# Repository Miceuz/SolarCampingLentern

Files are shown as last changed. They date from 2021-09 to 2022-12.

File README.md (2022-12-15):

# Open source Solar Camping Lantern

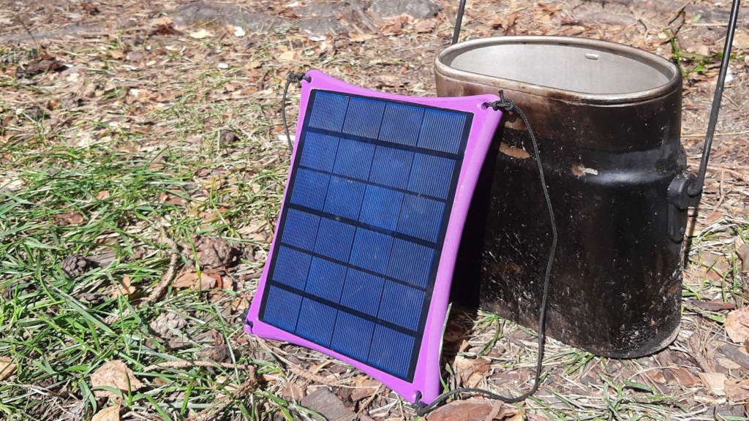
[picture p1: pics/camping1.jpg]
Open source Solar Camping Lantern


## Background

I started seeing a lot of disposable electronic cigarettes being used. As everyone knows, those devices contain perfectly rechargeable LiPo battery. And I've seen them thrown away everywhere - on streets, in general waste thrash cans, etc. While a lot of my friends have successfully refilled juice and re-charged the battery, the devices are not built to last - heating coil dies after several re-uses anyway. I have decided to look for a way to recycle those batteries. 

So I have decided to make a lantern for my camping needs and also investigate a product parameter space. The idea popped in to my mind during a summer music festival, actually. When you camp with your friends and need a bit of extra light in the camp at night. It was a sunny summer, so of course I had to have it solar powered. Provided unlimited supply of batteries, can it be self sufficient in it's power needs just from solar energy while still being manageable in camp environment?

It's always a good idea to check what's available at the market. Maybe there is a product on the market that does just that? Just a piece of my expenses, not worth spending my time?

## Initial requirements

 * Light output: ~100lm
 * Run time: min 4h
 * Battery: LiPo 3.7V ~2000mAh
 * Charging time: 6h

I have gauged the amount of needed light from my Lumilight pocket torch I have lost and my "cyclope" torch from Decathlon I got this year. 100lm is not a huge amount of light but still not that bad - it's enough to see people and stuff around, human eye is logarithmic and adapts to low light conditions.

Run time is a modest guess from a festival scenario - you might need light from 11 at night to 3 in the morning, roughly.

Charging time is a lazy day camping, maybe I will remember to pull it out and put on a sun sometime. It's not full effective sun time, just general time the device spends in sun semi-kinda-charging.

## Case studies

### [BioLite SunLight 100](https://www.bioliteenergy.com/products/sunlight-100?variant=1142597386254)

  * Light output: 100lm max
  * Battery: 750mAh LiPo
  * Run time: 3h
  * Solar pannel: 0.45W
  * Charging time: 7h
  * Dimensions: 85x86x23 mm
  * Weight: 95g
  * Price: 20$

### [MPOWERD Luci Outdoor 2.0](https://mpowerd.com/products/luci-outdoor-2-0-f2017)

 * Light output: 75lm
 * Battery: 1000mAh
 * Run time: 6h
 * Charging time: 7h
 * Dimensions: 127mm dia, 25mm height
 * Weight: 125g
 * Price: 24$

### [MPowerd Luci Solar String Lights](https://mpowerd.com/products/string-lights)

 * Light output: 100lm
 * Battery: 2000mAh
 * Charging time: 16h
 * Run time: 5h
 * Dimensions: 127mm dia, 50mm height
 * Weight: 320g
 * Price: 50$

There are devices that target the same light output I want. Some of these specifications are inferred as not all manufacturers provide all the information I needed. SunLight 100 does almost exactly what I want, but solar battery this size barely will produce 8.3Wh needed in 7h of charging time. All in all solar in all of these products seems to be a nice addition to USB charging, not the main power provider. 

Also I have bought some not-so-cheap crap from local hardware store that pretended like it can do what I want, but solar battery was total crap in those, outputting mere single digit milli-amps.

Thus, I have easily convinced myself that this is well worth as a hobby project. Besides, had to use those batteries up! So, with the battery sourcing question sorted out, let's not think about price too much and look what happens if we push on the light output efficiency and solar input efficiency.

## Design

### MPPT options

 * SPV1040T
 * ADP5090ACPZ-2-R7
 * BQ24650
 * [MPPT Solar Panel Controller with DC Converter](https://www.tindie.com/products/electronicstore/mppt-solar-panel-controller-with-dc-converter-2)

In the times of supply chain collapse, choosing a MMPT capable converter chip for storing solar energy to the battery was not an easy thing. They all are either not available or expensive. Luckily I have stumbled on this board by [PC Tech](https://www.tindie.com/stores/electronicstore/) featuring CN3791. Basically this project could have ended just there, as this board was all I needed - I have made my first prototype using it. Although I had to extract a bit more efficiency by having a dedicated led driver, also add some computer control to the thing. 

### Light Source

 * L130-4070003000W21 - Vf = 6V, I = 100mA, Light output = 100lm

It's one of the most efficient LEDs available at electronic distributors at the time. What's interesting and handy is that it's practically voltage controlled - it has a nice shallow IV curve. Provided you extract the heat from them though. They will happily do 100lm at 0.6W, the efficiency is even higher if you run them at half the rating. That's why I have doubled them up in my design.

Also I have decided to throw in a red light source, to see if it might be usable too. Red light does not dazzle humans too much, so it makes a good low level standby light source for the night. I did not want to add additional complication of channel switching for led driver chip, thus decided to power red led directly from MCU pin.

### Photovoltaics

 * [Solar panel](https://www.evita.lt/u-9045-saules-baterijos-modulis-6v-3-5w-165x135mm?search=saul%C4%97s) 6V, 3.5W

These panels, available at local suppliers, looked like a good trade-off between size and output power. Besides, not a lot to choose from, really. I have measured them and they were outputting the rated power, but it dropped drastically with non-perfect orientation to the sun, thus it has to be de-rated significantly. I have guesstimated MPPT point of the panel to be somewhere at 80% of it's open circuit voltage and measured about the same with a potentiometer hooked up to it.

### Power

**If you replicate this design, be warned that battery failure is a risk to be considered!**

 * Battery: 3.7 LiPo, capacity varies: 1.4Wh, 1.85Wh, total capacity up to 11Wh
 * MCU powered directly from battery
 * DC-DC led driver - MCP1664

Batteries are re-used from electronic cigarettes. I don't really know if they retain their safety ratings after they have been re-charged, but people around are re-charging them and I've heard of no fires happening. 

They come with a protection board and I have tried shorting and over-discharging them - seem to work fine, also I've seen my friends ridiculously abusing them with high charge currents on par of 3C. Their longevity is to be proven though as they might not be optimized for a lot of re-charge cycles, but it seems their safety is on par with standards mandatory with CE marking. I am happy to delay their travel to a landfill or a recycler.  

### Operational parameters

 * Energy consumed: 0.1A * 6V * 4h = 2.4Wh
 * Solar power available: 3.5W minus conversion losses
 * Light output: 120lm

It has plenty of solar - 1h of perfect sunlight should provide enough of charge for 4 required hours. Seems to make sense to have more battery capacity, but there is a small trade-off with the weight. It will be interesting to experiment with battery sizes and see what run times are achievable.

### Mechanical construction

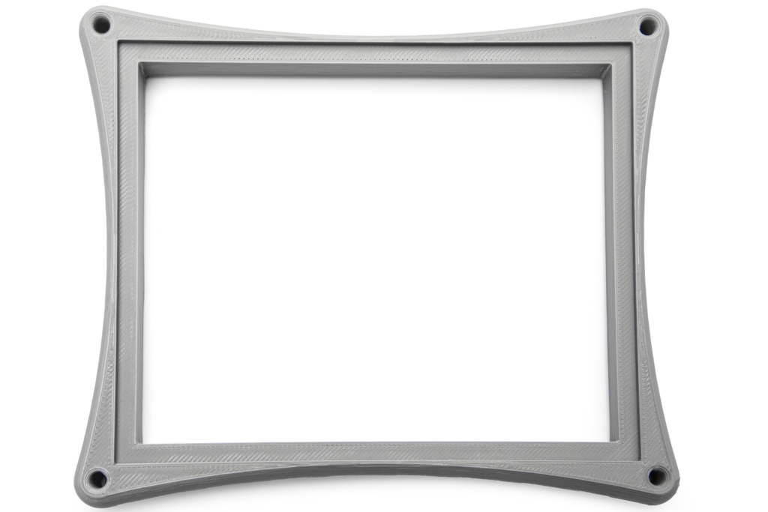
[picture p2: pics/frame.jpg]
Frame of Solar Camping Lantern


Size and shape of the device is dictated by the solar panel. Since I wanted a lot of solar power, I knew I will not be able to make it as compact as commercially available devices. Also mechanical side of things is not my strength, so I went for a simple flat panel. One of use cases for such a light would be as a coaster for a water bottle - that makes a pretty nice low effort table light. Also I've added 4 holes to attach the lantern with rope - to a branch or a tarp. 

All assembly is glue based (blergh!). Batteries are glued to the PCB. PCB is glued and soldered to the solar panel. Both the solar panel and plexiglass are glued to a 3D printed plastic frame.

Considering the usage scenario, of course it should have some level of ingress protection. Provided all glue seams are tight (sic!), the only place for water to seep in is through a button hole. I am going to experiment with printing of the frame from flexible plastics and have the button hole closed, but for the first revision there's going to be a small seam between hole and plunger and IPX6 rated button behind it.

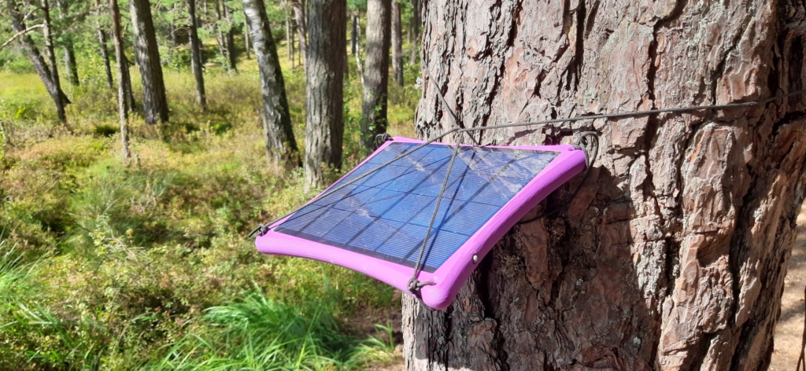
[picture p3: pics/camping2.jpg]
Solar Camping Lantern attached to a tree for charging


### MCU and software

I have chosen my beloved attiny441 - I have a stock of them and I am used to them and it's a relief to spend some time in a simple naive world of 8-bit microcontrollers. It's pretty low power too.

Software functions:

 * On/Off
 * Different levels of lighting
 * Cycle through white and red leds
 * Indicate battery level via charlieplexed leds
 * Auto level reduction on low battery [todo]
 * Fade everywhere [todo]
 * Sky's the limit, what can you do with a single button interface?

### Bells and whistles

 * Charlieplexed leds for battery level indication

### Weight analysis

| Item | Weight, g |
|---|---|
| 3.5W solar panel | 96 |
| Plexiglass | 73 |
| Frame | 56 |
| PCB 0.8mm | 36 |
| Battery 380mAh 7g, 3pack | 22 |
| Electronic components | 4 |
| Glue | 10 |
| **Total** | **297** |

## BOM Price analysis

| Item | Price, € |
|---|---|
| Solar panel | 13 |
| Electronic components | 6.3 |
| PCB | 5.1 |
| Frame | 2 |
| Plexiglass | 0.6 |
| Batteries | 0 |
| **Total** | **27** | 

Prices are for a small batch of 10 units.

## Final specifications

 * Light output: 120lm
 * Battery: LiPo 3.7V up to 4000mAh 
 * Run time: >4h
 * Solar pannel: 3.5W
 * Charging time for 4h run time: 1h (perfect sun conditions)
 * Dimensions: 193x163x15 mm
 * Weight: 297g
 * BOM Price: 27€

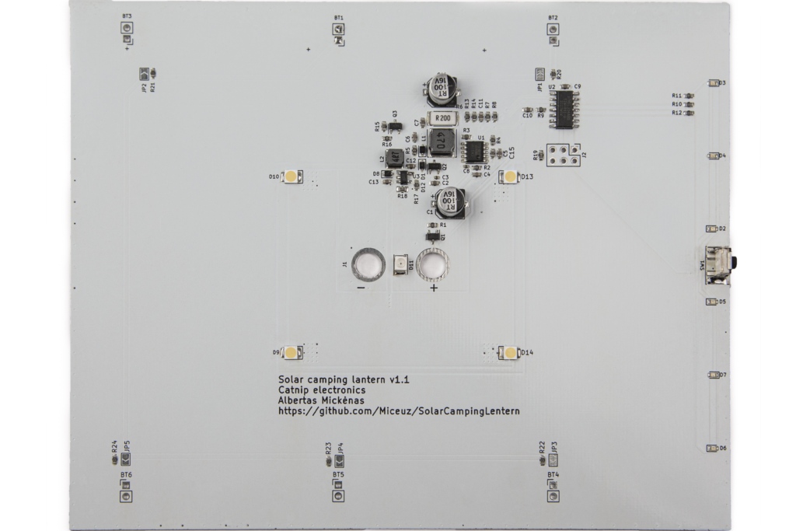
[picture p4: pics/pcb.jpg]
PCB of Solar Camping Lantern


## Conclusion

I took me 3 PCB iterations to get it right, I had to adjust a button position so it's easier to find in the dark, also I had to spread battery level indication leds along the edge so they would be distinguishable behind the plexiglass. Finally I have used 4 while leds instead of two, also spaced out as the single light source was a bit too strong. 

Weight is a concern, but here I am limited to materials I have access to. I have made some improvements by using a 0.8mm PCB, maybe I can make the frame lighter, but the real limiting factors are solar pannel and plexiglass.

I have tried using the first prototype while camping at sunny autumn and it proved to be working very well. Working time with 870mAh battery was a little too short for long autumn evenings at full 100lm, but it was able to fully charge during the next day. Later I brought the panel to a rainy camping trip in December. Panel was barely charging the 5.5Ah battery, but it held almost two evenings allowing us to set up camp, prepare wood and chill under the red light in addition to fire. I think it's not much useful for rainy winter in Easter Europe, but it will be a perfect light for summer camping.

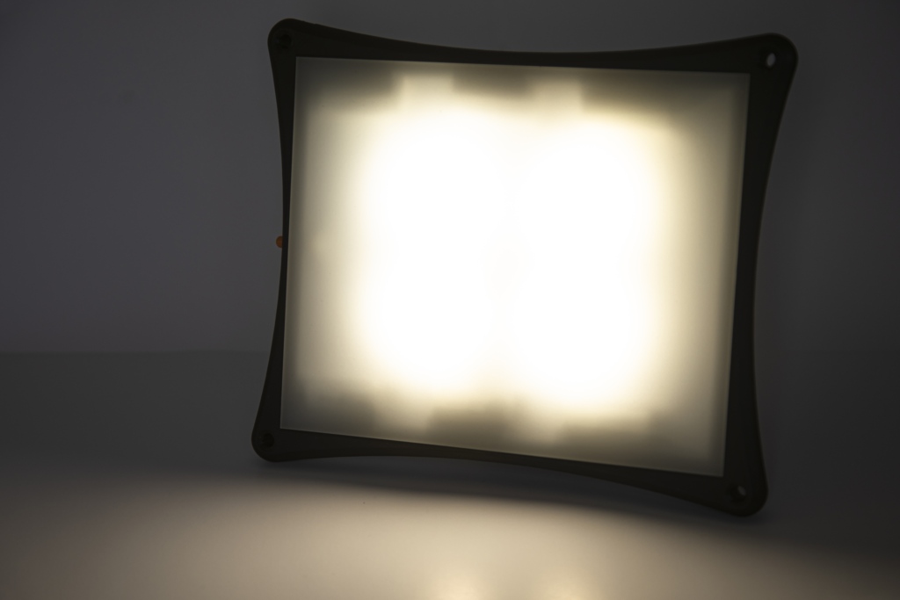
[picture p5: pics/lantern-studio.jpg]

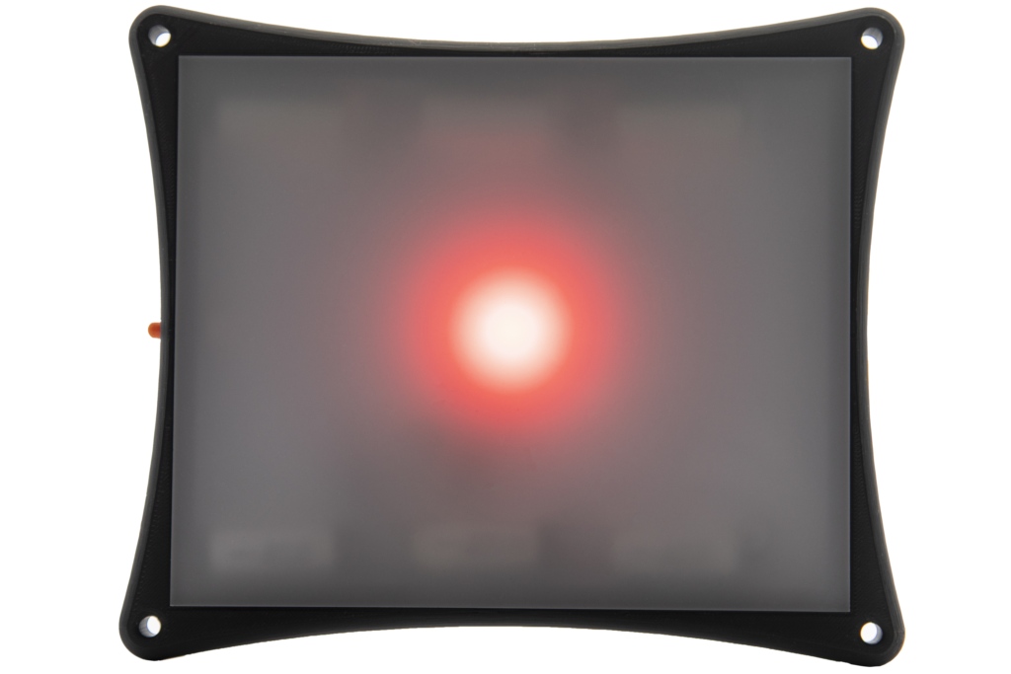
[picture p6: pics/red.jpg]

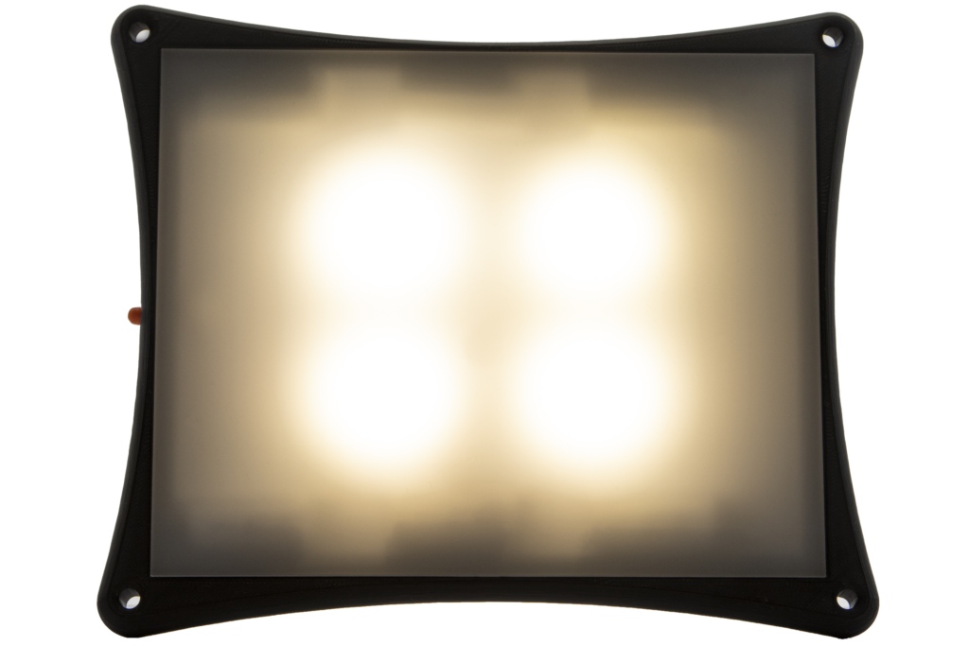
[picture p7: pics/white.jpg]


## Licence

[CERN Open Hardware Licence Version 2 - Strongly Reciprocal](https://ohwr.org/cern_ohl_s_v2.txt)

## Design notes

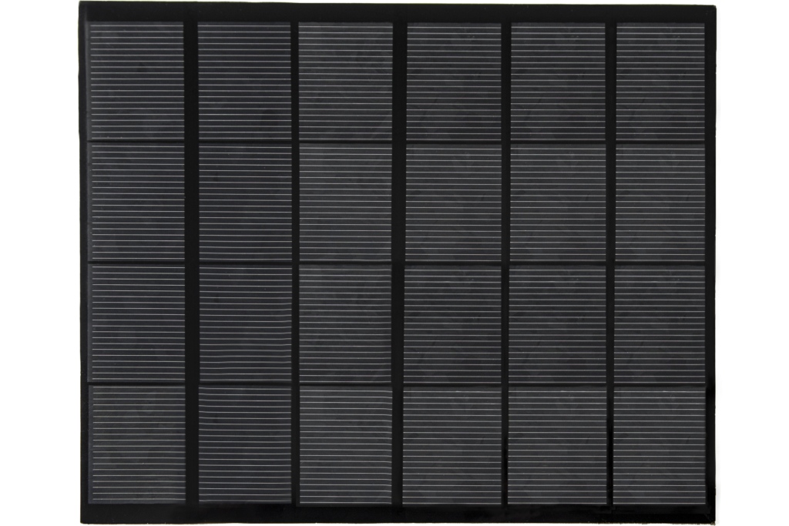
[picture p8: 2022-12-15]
pics/solar-pannel.jpg

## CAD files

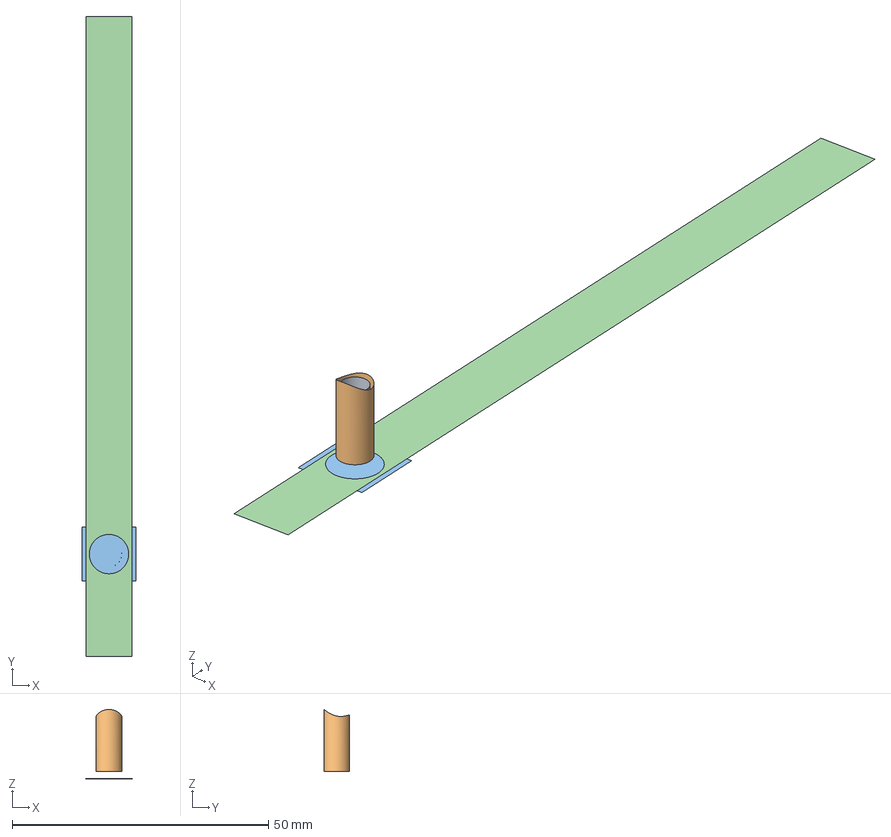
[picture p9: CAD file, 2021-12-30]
mechanical/plunger-assembly.FCStd
10.6 x 125.0 x 13.5 mm
_Element
_Element001
XY_Plane@Body
_Element003

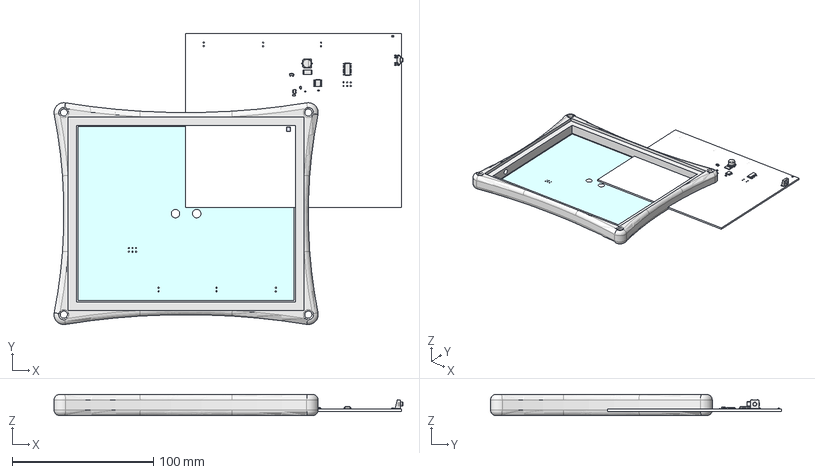
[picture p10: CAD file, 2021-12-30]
mechanical/assembly.FCStd
247.0 x 206.0 x 15.0 mm
D10_3030-017 UNIT SIZE product (Adjust Origin) 26Sept19_c236f93da869
C14_CP_Elec_63x54_Nichicon_5161770a203f
C4_C_0603_1608Metric_8aaf7dfd186b
R1_R_0603_1608Metric_b76f0809609e
D3_D_0603_a9e88e545611
C3_C_0402_1005Metric_6a8e8e6d586b
Q3_SOT_23_0002a45287e3
D11_CLVBA-FKA-CAEDH8BBB7A363_9ca18516bff6
D12_D_SOD_323_f1b1cf5ceba4
R18_R_0805_2012Metric_6b706fde28c5
R6_R_2512_6332Metric_f1aa6a1b5782
U1_SSOP_10_39x49mm_P100mm_f70d7e3d2787
U2_SOIC_14_39x87mm_P127mm_84519712cec0
U3_SOT_23_5_c68c99c74113
SW1_C-1571407-2_2a826a100a5c
_Element
_Element001

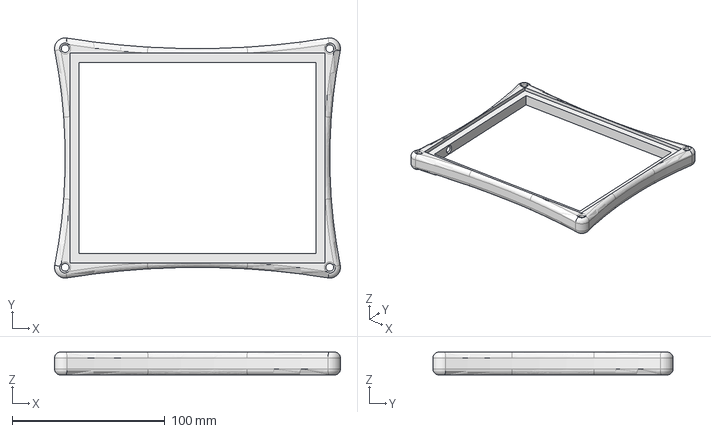
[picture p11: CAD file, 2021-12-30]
mechanical/bezel2-chmfer.FCStd
187.0 x 157.0 x 15.0 mm

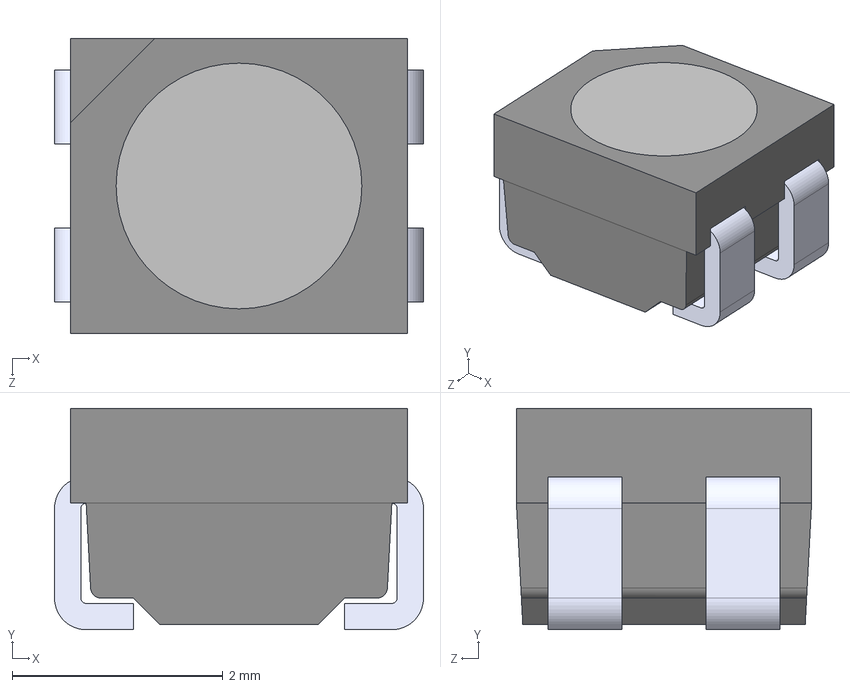
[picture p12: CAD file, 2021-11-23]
solar_lantern/3d/CLA1B-MKW-XD0E0E73.STEP
3.50 x 2.10 x 2.80 mm

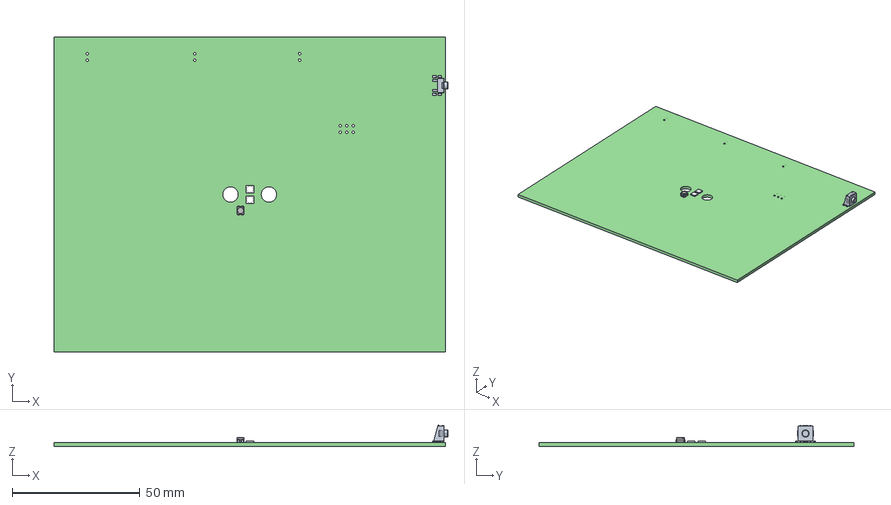
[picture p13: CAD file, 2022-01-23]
solar_lantern/solar_lantern.step
154.0 x 123.0 x 8.35 mm
solar_lantern PCB

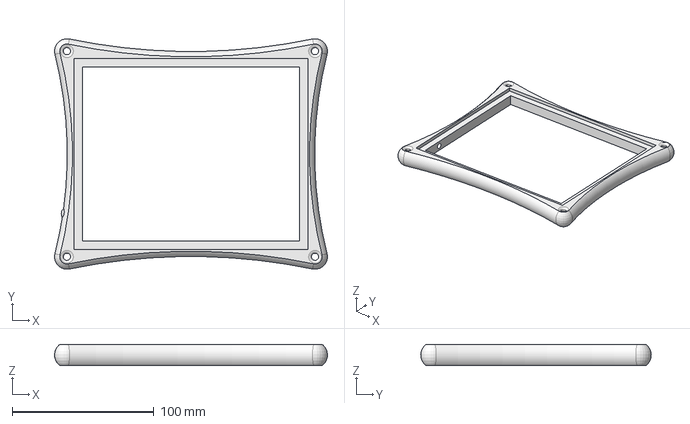
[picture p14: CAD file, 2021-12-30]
mechanical/bezel4.FCStd
192.8 x 162.8 x 15.0 mm

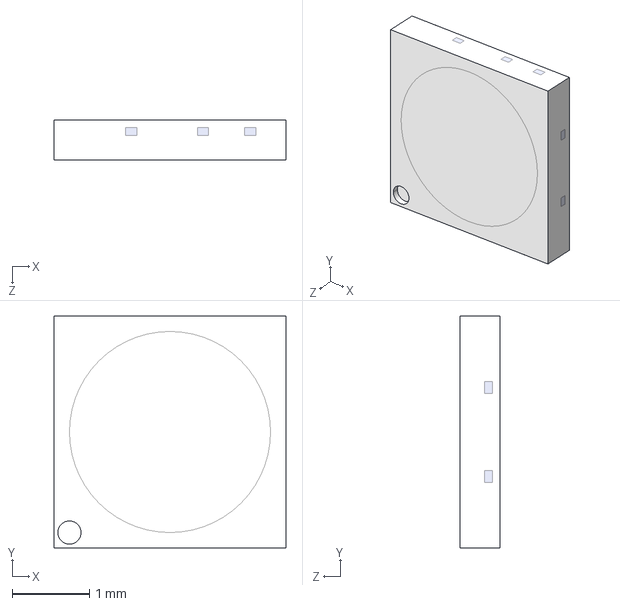
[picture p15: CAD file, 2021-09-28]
solar_lantern/3d/LUXEON 3030 2D Round LES.step
3.00 x 3.00 x 0.523 mm

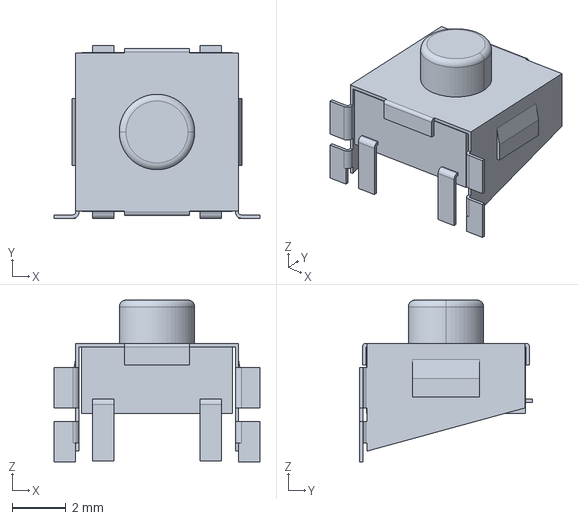
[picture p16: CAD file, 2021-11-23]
solar_lantern/c-1571407-2-j-3d.stp
7.64 x 6.40 x 6.00 mm

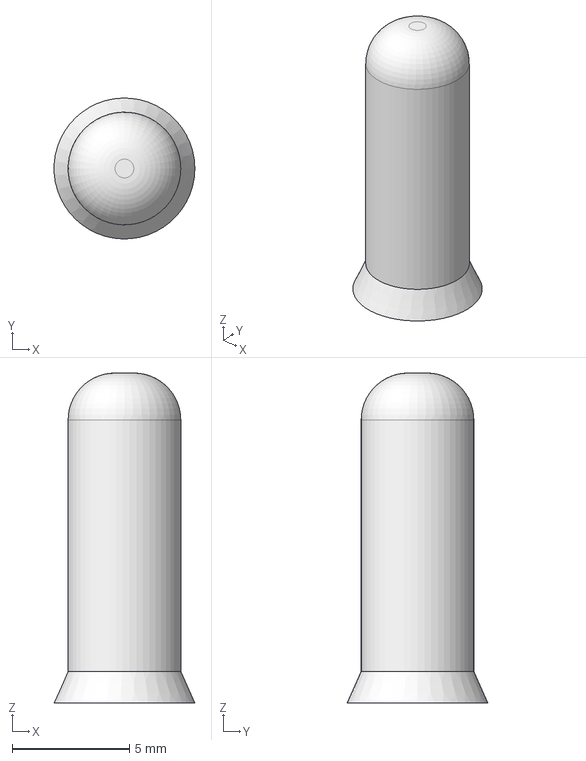
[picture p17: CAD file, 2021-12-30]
mechanical/plunger.FCStd
5.99 x 6.00 x 14.0 mm

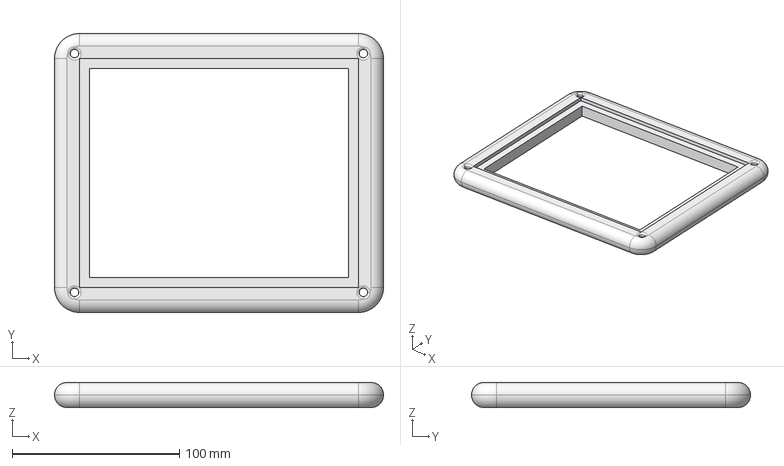
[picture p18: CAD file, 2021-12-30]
mechanical/bezel.FCStd
197.0 x 167.0 x 15.0 mm

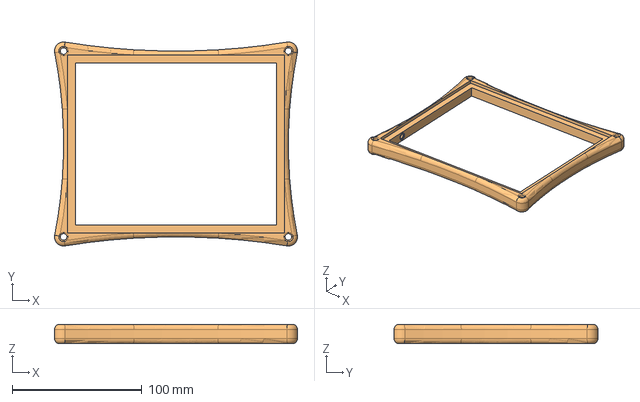
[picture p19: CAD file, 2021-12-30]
mechanical/bezel2.FCStd
187.0 x 157.0 x 15.0 mm

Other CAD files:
mechanical/bezel3.FCStd
mechanical/bezel2-Body.3mf
mechanical/plunger-BodySketch.stl
mechanical/plunger-Body.3mf
mechanical/bezel-Body.3mf
mechanical/bezel3-Body.3mf
mechanical/bezel3-Body.stl
mechanical/plunger-Body.stl

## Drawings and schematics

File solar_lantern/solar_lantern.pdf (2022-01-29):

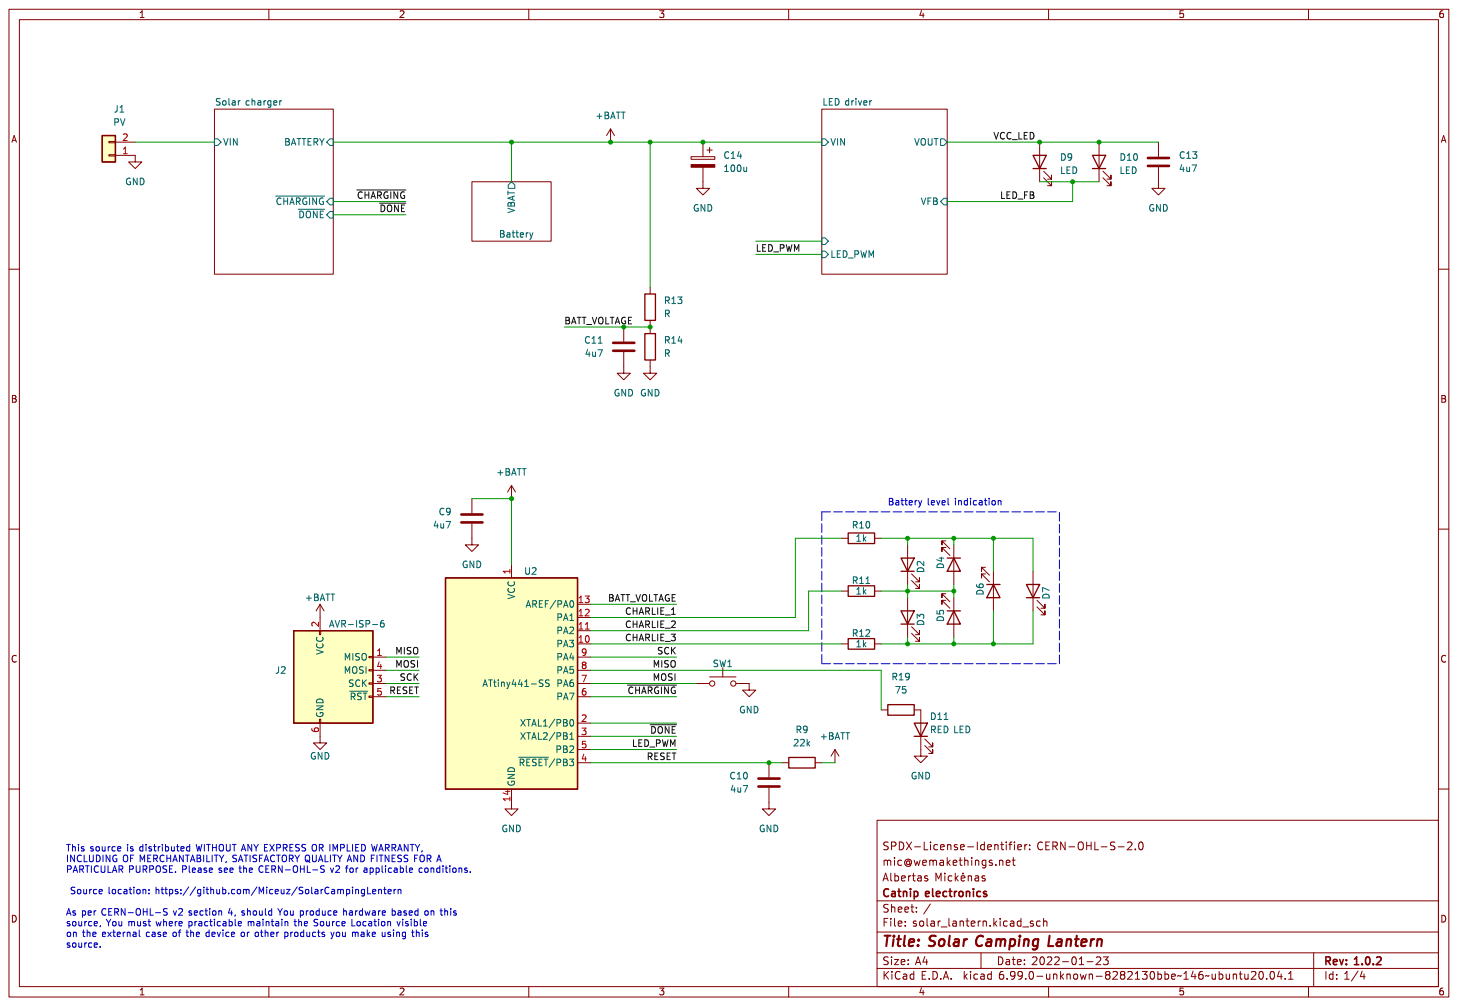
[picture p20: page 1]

1 PA3 10 PA2 11 PA1 12 AREF/PA0 13 GND 14 XTAL1/PB0 2 XTAL2/PB1 3 ~{RESET}/PB3 4 PB2 5 PA7 6 PA6 7 PA5 8 PA4 9 U2 ATtiny441-SS GND GND GND

2 SCK 3 MOSI 4 ~{RST} 5 GND

mic@wemakethings.net SPDX-License-Identifier: CERN-OHL-S-2.0

INCLUDING OF MERCHANTABILITY, SATISFACTORY QUALITY AND FITNESS FOR A PARTICULAR PURPOSE. Please see the CERN-OHL-S v2 for applicable conditions.

File: solar_lantern.kicad_sch Sheet: / Catnip electronics

Source location: https://github.com/Miceuz/SolarCampingLentern

As per CERN-OHL-S v2 section 4, should You produce hardware based on this
source, You must where practicable maintain the Source Location visible
on the external case of the device or other products you make using this source.

Id: 1/4 Title: Solar Camping Lantern

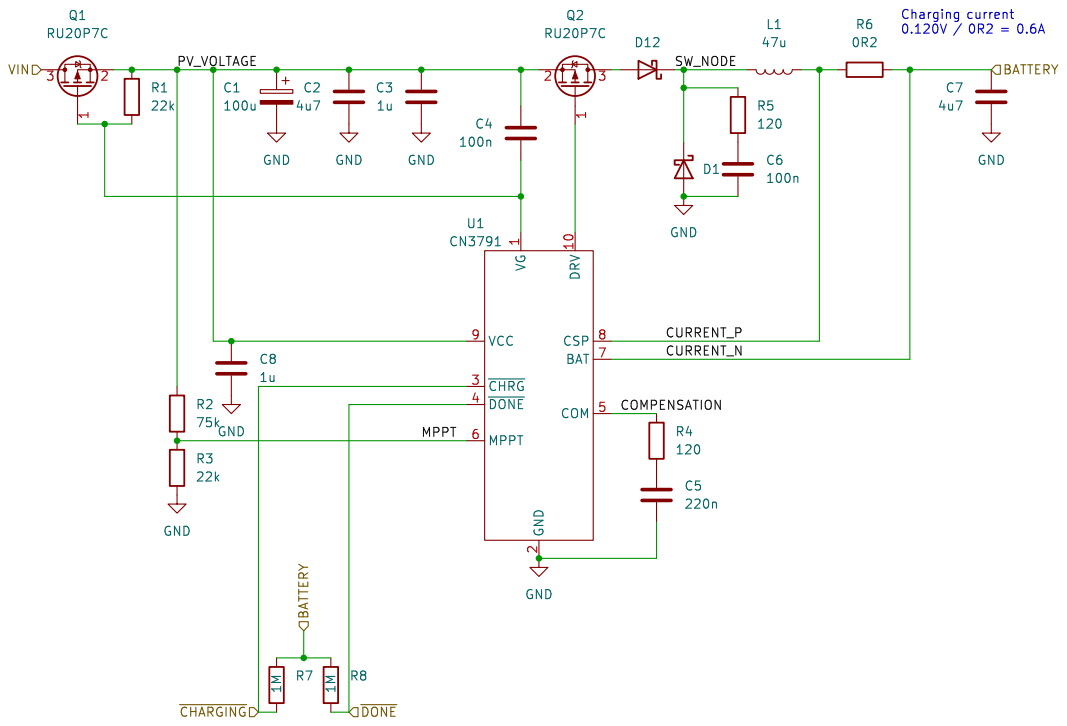
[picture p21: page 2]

2 ~{CHRG} 3 ~{DONE} 4 COM 5 MPPT 6 BAT 7 CSP 8 VCC 9U1 CN3791 D12

mic@wemakethings.net
Catnip electronics
Sheet: /Solar charger/
File: solar_charger.kicad_sch
Id: 2/4 Title: Solar MPPT charger

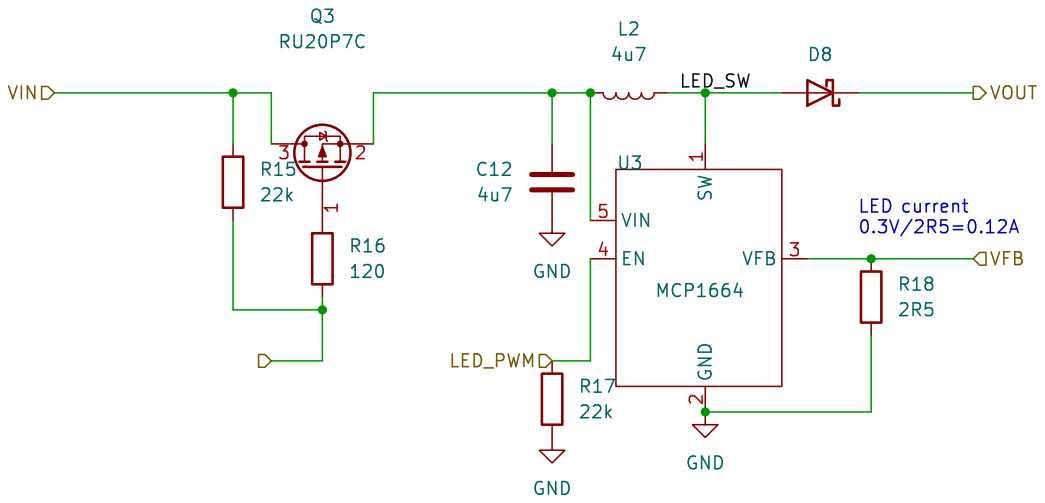
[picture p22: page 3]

2 VFB 3 EN 4 VIN 5 U3 MCP1664 D8 ~{LED_EN} VIN VOUT VFB

mic@wemakethings.net
File: led_driver.kicad_sch Sheet: /LED driver/ Catnip electronics

Id: 3/4 Title: LED driver

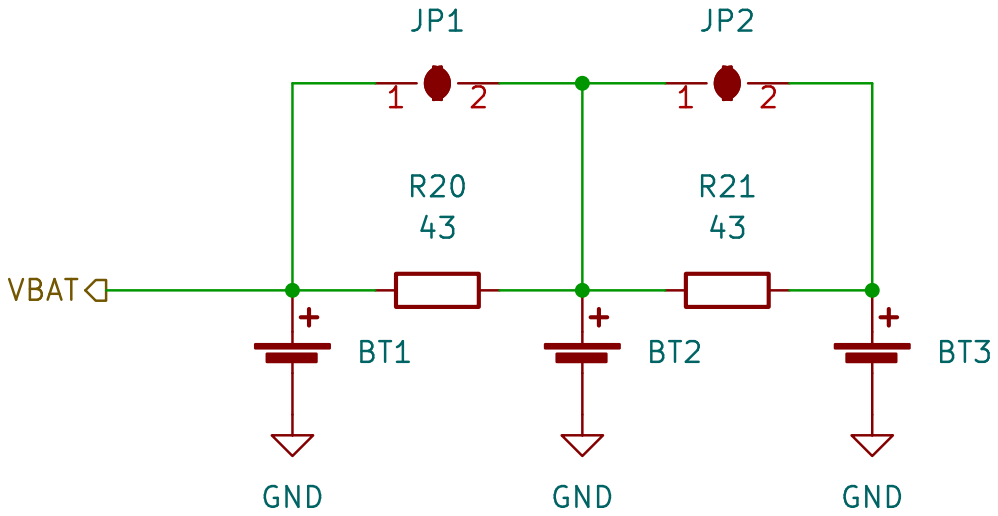
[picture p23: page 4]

mic@wemakethings.net
Catnip electronics
Sheet: /Battery/
File: battery.kicad_sch
Id: 4/4 Title: Battery interconnect

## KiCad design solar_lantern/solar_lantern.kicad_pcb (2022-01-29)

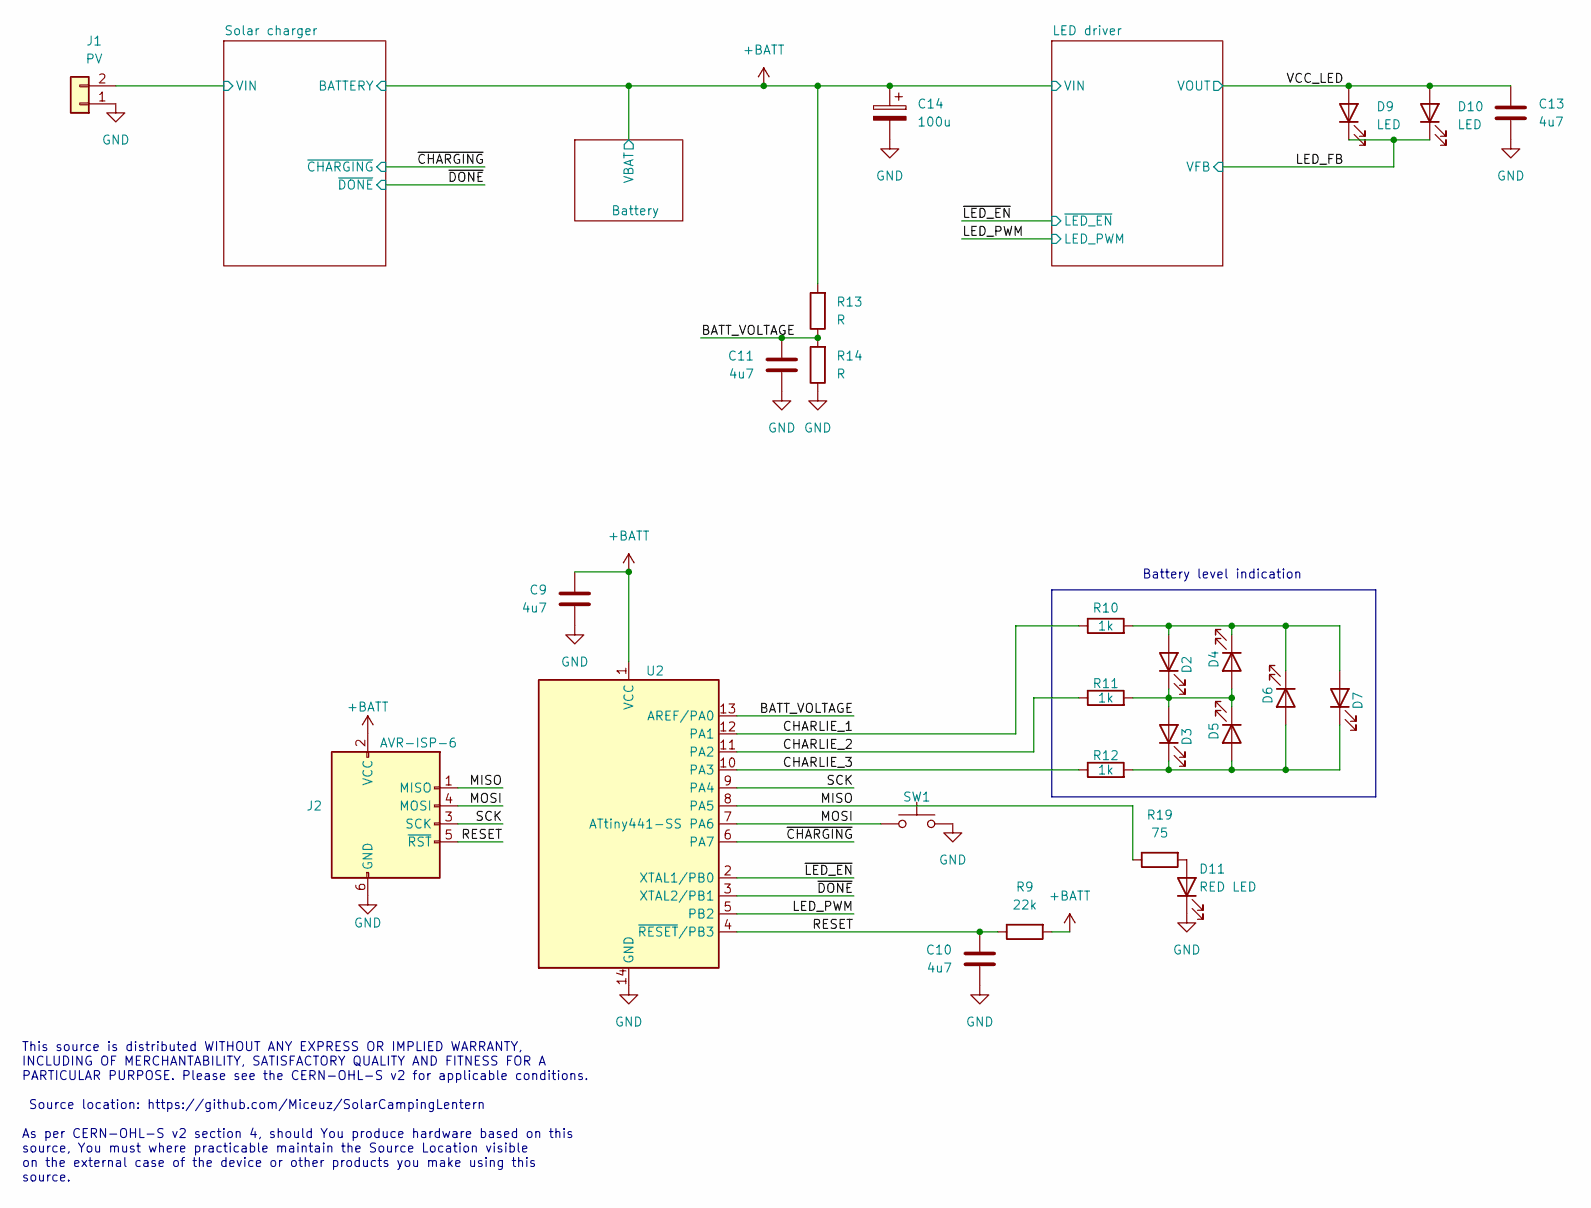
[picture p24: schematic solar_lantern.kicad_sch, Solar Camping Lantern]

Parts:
C9, C10, C11, C13: 4u7; C_0603_1608Metric
C14: 100u; CP_Elec_6.3x5.4_Nichicon; PartNo EEV107M016S9GAA
D2, D3, D4, D5, D6, D7: LED; D_0603_1608Metric
D9, D10: LED; DS207; PartNo L130-4070003000W21
D11: RED LED; LED_PLCC-2; PartNo CLM1B-RKW-CUbVbAA3
J1: PV; PinHeader_1x02_P2.54mm_Vertical
J2: AVR-ISP-6; PinHeader_2x03_P2.54mm_Vertical
R9: 22k; R_0603_1608Metric
R10, R11, R12: 1k; R_0603_1608Metric
R13, R14: R; R_0603_1608Metric
R19: 75; R_0603_1608Metric
SW1: SW_Push; SW_Push_1P1T_NO_6x6mm_H9.5mm; PartNo 1571407-2
U2: ATtiny441-SS; SOIC-14_3.9x8.7mm_P1.27mm

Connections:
+BATT: C9.2, C14.1, J2.2 (VCC), R9.2, R13.2, U2.1 (VCC); also elsewhere on the board
/BATT_VOLTAGE: C11.2, R13.1, R14.2, U2.13 (AREF/PA0)
/CHARLIE_1: R10.1, U2.12 (PA1)
/CHARLIE_2: R11.1, U2.11 (PA2)
/CHARLIE_3: R12.1, U2.10 (PA3)
/LED_FB: D9.1 (K), D10.1 (K); also elsewhere on the board
/LED_PWM: U2.5 (PB2); also elsewhere on the board
/MISO: J2.1 (MISO), R19.1, U2.8 (PA5)
/MOSI: J2.4 (MOSI), SW1.1, U2.7 (PA6)
/RESET: C10.2, J2.5 (~RST), R9.1, U2.4 (~RESET/PB3)
/SCK: J2.3 (SCK), U2.9 (PA4)
/Solar charger/VIN: J1.2; also elsewhere on the board
/VCC_LED: C13.1, D9.2 (A), D10.2 (A); also elsewhere on the board
/~CHARGING: U2.6 (PA7); also elsewhere on the board
/~DONE: U2.3 (XTAL2/PB1); also elsewhere on the board
/~LED_EN: U2.2 (XTAL1/PB0); also elsewhere on the board
GND: C9.1, C10.1, C11.1, C13.2, C14.2, D11.2 (K), J1.1, J2.6 (GND), R14.1, SW1.2, U2.14 (GND); also elsewhere on the board
unnamed: D2.1 (K), D3.2 (A), D4.2 (A), D5.1 (K), R11.2
unnamed: D2.2 (A), D4.1 (K), D6.1 (K), D7.2 (A), R10.2
unnamed: D3.1 (K), D5.2 (A), D6.2 (A), D7.1 (K), R12.2
unnamed: D11.1 (A), R19.2

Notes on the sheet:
This source is distributed WITHOUT ANY EXPRESS OR IMPLIED WARRANTY, INCLUDING OF MERCHANTABILITY, SATISFACTORY QUALITY AND FITNESS FOR A PARTICULAR PURPOSE. Please see the CERN-OHL-S v2 for applicable conditions. Source location: https://github.com/Miceuz/SolarCampingLentern As per CERN-OHL-S v2 se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
Battery level indication

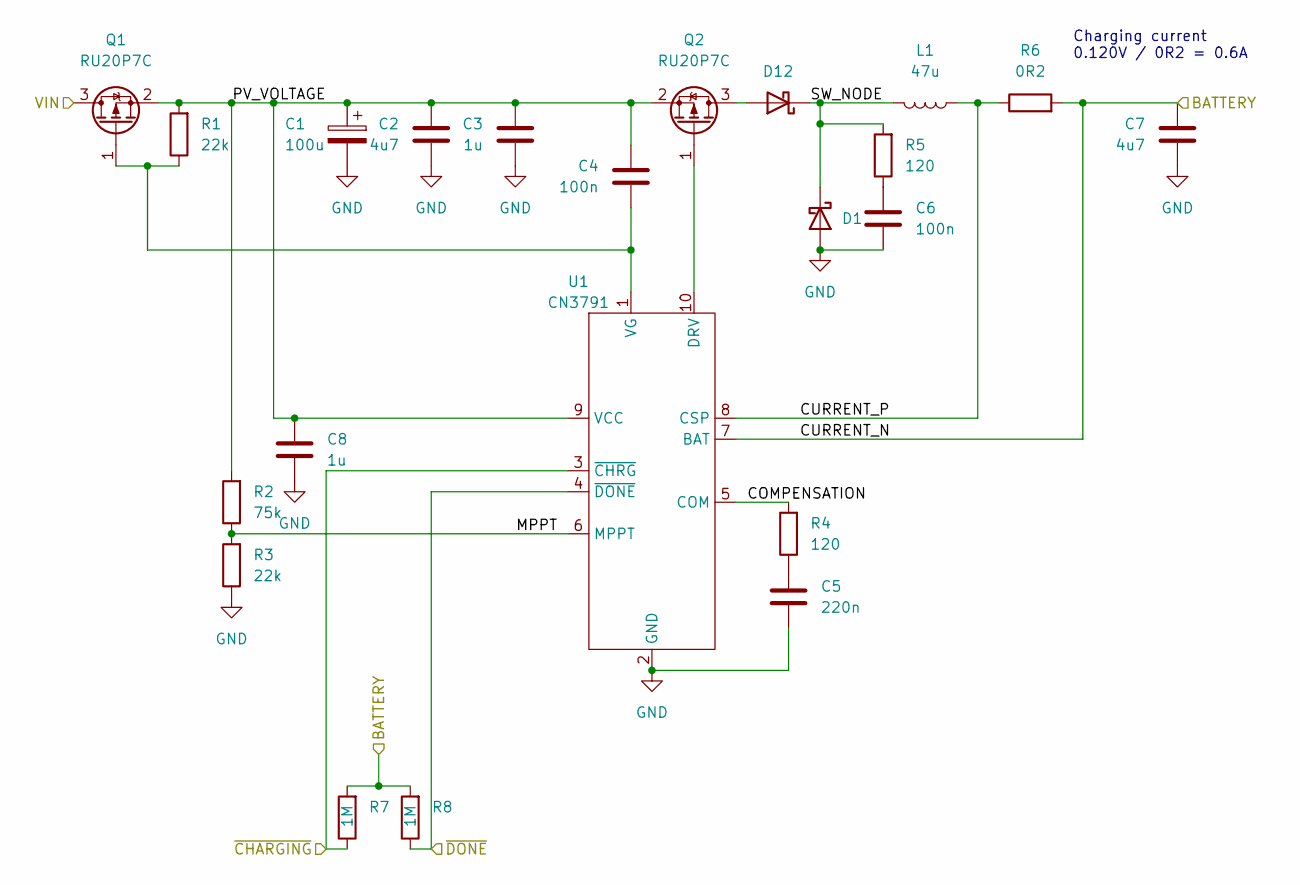
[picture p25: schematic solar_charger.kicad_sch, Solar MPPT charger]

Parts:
C1: 100u; CP_Elec_6.3x5.4_Nichicon; PartNo EEV107M016S9GAA
C2, C7: 4u7; C_0603_1608Metric
C3, C8: 1u; C_0402_1005Metric
C4, C6: 100n; C_0603_1608Metric
C5: 220n; C_0603_1608Metric
D1, D12: D_Schottky; D_SOD-323
L1: 47u; L_Coilcraft_XAL60xx_6.36x6.56mm
Q1, Q2: RU20P7C; SOT-23
R1, R3: 22k; R_0603_1608Metric
R2: 75k; R_0603_1608Metric
R4, R5: 120; R_0603_1608Metric
R6: 0R2; R_2512_6332Metric
R7, R8: 1M; R_0603_1608Metric
U1: CN3791; SSOP-10_3.9x4.9mm_P1.00mm

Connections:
+BATT: C7.2, R6.2, R7.2, R8.2, U1.7 (BAT); also elsewhere on the board
/Solar charger/COMPENSATION: R4.2, U1.5 (COM)
/Solar charger/CURRENT_P: L1.2, R6.1, U1.8 (CSP)
/Solar charger/MPPT: R2.1, R3.2, U1.6 (MPPT)
/Solar charger/PV_VOLTAGE: C1.1, C2.2, C3.2, C4.2, C8.2, Q1.2 (S), Q2.2 (S), R1.2, R2.2, U1.9 (VCC)
/Solar charger/SW_NODE: D1.1 (K), D12.1 (K), L1.1, R5.2
/Solar charger/VIN: Q1.3 (D); also elsewhere on the board
/~CHARGING: R7.1, U1.3 (~CHRG); also elsewhere on the board
/~DONE: R8.1, U1.4 (~DONE); also elsewhere on the board
GND: C1.2, C2.1, C3.1, C5.1, C6.1, C7.1, C8.1, D1.2 (A), R3.1, U1.2 (GND); also elsewhere on the board
unnamed: C4.1, Q1.1 (G), R1.1, U1.1 (VG)
unnamed: C5.2, R4.1
unnamed: C6.2, R5.1
unnamed: Q2.1 (G), U1.10 (DRV)
unnamed: D12.2 (A), Q2.3 (D)

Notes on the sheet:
Charging current 0.120V / 0R2 = 0.6A

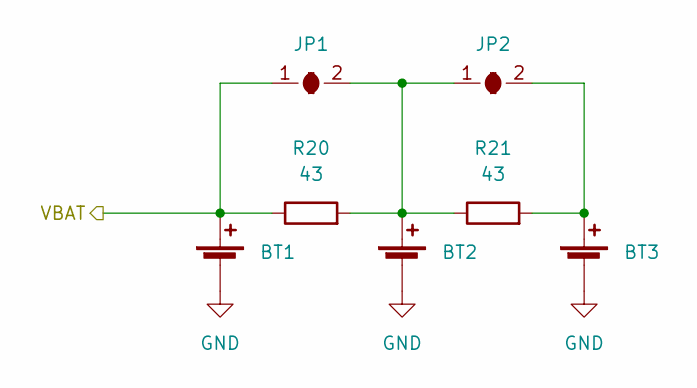
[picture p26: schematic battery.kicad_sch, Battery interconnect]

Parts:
BT1, BT2, BT3: Battery_Cell; PinHeader_1x02_P2.54mm_Vertical
JP1, JP2: SolderJumper_2_Open; SolderJumper-2_P1.3mm_Open_TrianglePad1.0x1.5mm
R20, R21: 43; R_0603_1608Metric; PartNo SDR03EZPJ430

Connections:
+BATT: BT1.1 (+), JP1.1 (A), R20.1; also elsewhere on the board
GND: BT1.2 (-), BT2.2 (-), BT3.2 (-); also elsewhere on the board
unnamed: BT2.1 (+), JP1.2 (B), JP2.1 (A), R20.2, R21.1
unnamed: BT3.1 (+), JP2.2 (B), R21.2

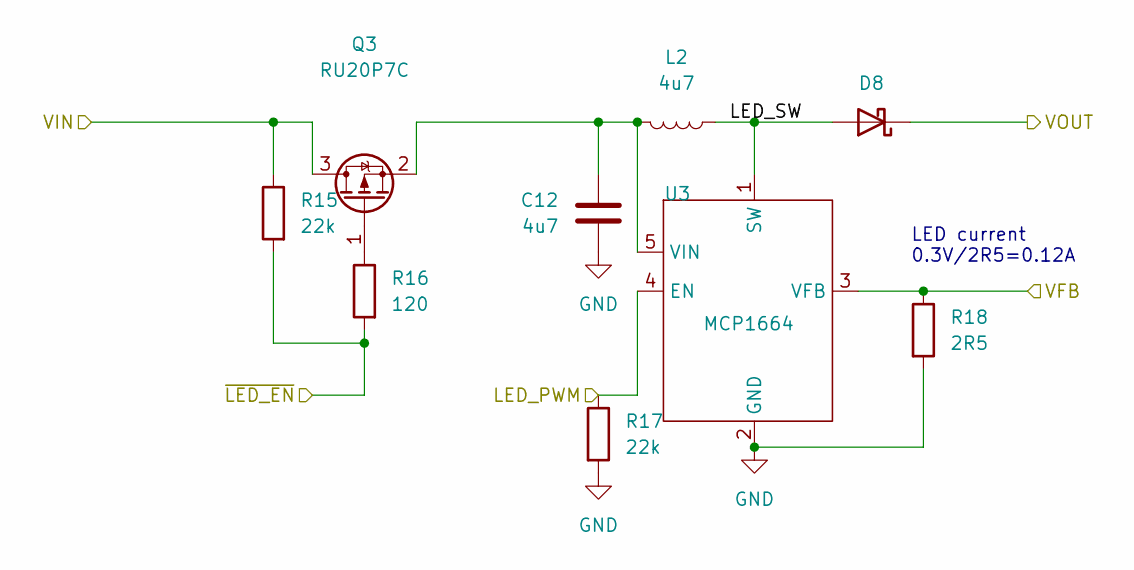
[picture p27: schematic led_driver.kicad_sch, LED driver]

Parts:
C12: 4u7; C_0603_1608Metric
D8: D_Schottky; D_SOD-323
L2: 4u7; L_Taiyo-Yuden_MD-4040; PartNo VLCF4020T-4R7N1R2
Q3: RU20P7C; SOT-23
R15, R17: 22k; R_0603_1608Metric
R16: 120; R_0603_1608Metric
R18: 2R5; R_0805_2012Metric; PartNo CRCW08052R49FKEA
U3: MCP1664; SOT-23-5

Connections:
+BATT: Q3.3 (D), R15.1; also elsewhere on the board
/LED driver/LED_SW: D8.2 (A), L2.2, U3.1 (SW)
/LED_FB: R18.1, U3.3 (VFB); also elsewhere on the board
/LED_PWM: R17.1, U3.4 (EN); also elsewhere on the board
/VCC_LED: D8.1 (K); also elsewhere on the board
/~LED_EN: R15.2, R16.2; also elsewhere on the board
GND: C12.1, R17.2, R18.2, U3.2 (GND); also elsewhere on the board
unnamed: C12.2, L2.1, Q3.2 (S), U3.5 (VIN)
unnamed: Q3.1 (G), R16.1

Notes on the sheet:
LED current 0.3V/2R5=0.12A

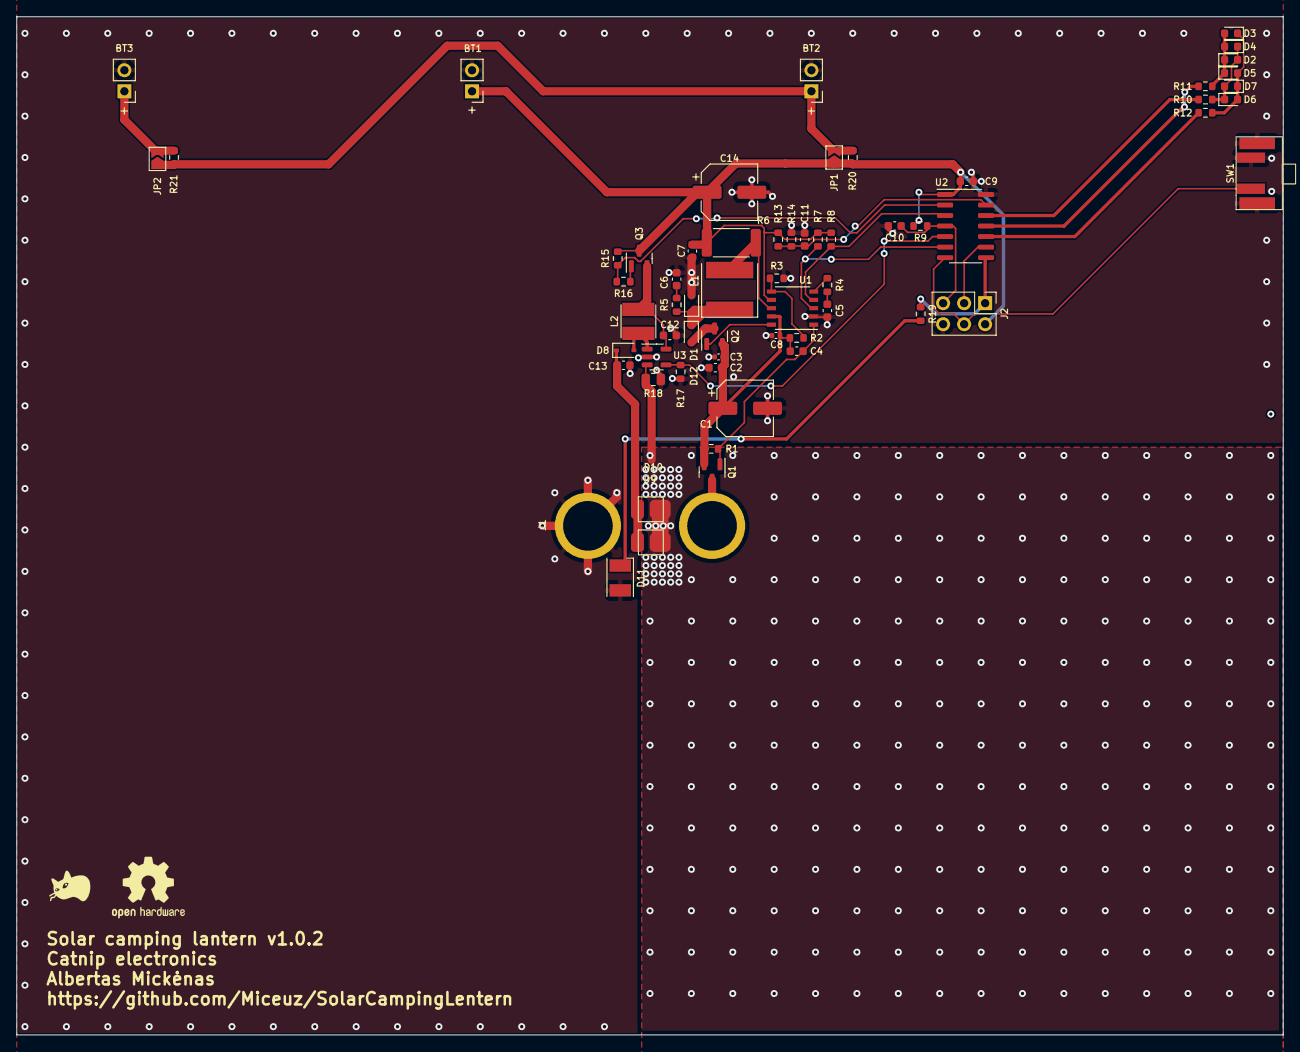
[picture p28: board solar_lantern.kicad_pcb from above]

Board: 2 copper layers, 153.0 x 123.0 mm, 63 parts (0 on the bottom side), 36 nets.

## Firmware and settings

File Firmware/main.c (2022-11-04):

/*
 ------------------------------------------------------------------------------
| Copyright Albertas Mickėnas 2022                                             |
|                                                                              |
| This source describes Open Hardware and is licensed under the CERN-OHL-S v2. |
|                                                                              |
| You may redistribute and modify this source and make products using it under |
| the terms of the CERN-OHL-S v2 (https://ohwr.org/cern_ohl_s_v2.txt).         |
|                                                                              |
| This source is distributed WITHOUT ANY EXPRESS OR IMPLIED WARRANTY,          |
| INCLUDING OF MERCHANTABILITY, SATISFACTORY QUALITY AND FITNESS FOR A         |
| PARTICULAR PURPOSE. Please see the CERN-OHL-S v2 for applicable conditions.  |
|                                                                              |
| Source location: https://https://github.com/Miceuz/SolarCampingLentern       |
|                                                                              |
| As per CERN-OHL-S v2 section 4, should You produce hardware based on this    |
| source, You must where practicable maintain the Source Location visible      |
| on the external case of the device or other products you make using this     |
| source.                                                                      |
 ------------------------------------------------------------------------------
*/

#include <stdbool.h> /* For true/false definition */
#include <stdint.h>  /* For uint8_t definition */

#include <avr/interrupt.h>
#include <avr/io.h>
#include <avr/pgmspace.h>
#include <avr/sleep.h>
#include <avr/wdt.h>
#include <stdlib.h>
#include <util/delay.h>

#include "debounce.h"
#include "millis.h"

const uint16_t PROGMEM gamma8[] = {
    0,   0,   0,   0,   0,   0,   0,   0,   1,   1,   1,   1,   1,   2,    2,
    2,   3,   3,   3,   4,   4,   5,   5,   5,   6,   7,   7,   8,   8,    9,
    10,  10,  11,  12,  13,  13,  14,  15,  16,  17,  18,  19,  20,  21,   22,
    23,  24,  25,  27,  28,  29,  30,  32,  33,  34,  36,  37,  39,  40,   42,
    43,  45,  46,  48,  50,  52,  53,  55,  57,  59,  61,  62,  64,  66,   68,
    70,  72,  75,  77,  79,  81,  83,  85,  88,  90,  92,  95,  97,  100,  102,
    105, 107, 110, 112, 115, 118, 121, 123, 126, 129, 132, 135, 138, 141,  144,
    147, 150, 153, 156, 159, 162, 166, 169, 172, 175, 179, 182, 186, 189,  193,
    196, 200, 203, 207, 211, 215, 218, 222, 226, 230, 234, 238, 242, 246,  250,
    254, 258, 262, 266, 271, 275, 279, 284, 288, 292, 297, 301, 306, 311,  315,
    320, 324, 329, 334, 339, 344, 348, 353, 358, 363, 368, 373, 378, 384,  389,
    394, 399, 405, 410, 415, 421, 426, 432, 437, 443, 448, 454, 459, 465,  471,
    477, 483, 488, 494, 500, 506, 512, 518, 524, 530, 537, 543, 549, 555,  562,
    568, 575, 581, 587, 594, 601, 607, 614, 620, 627, 634, 641, 648, 654,  661,
    668, 675, 682, 689, 697, 704, 711, 718, 725, 733, 740, 747, 755, 762,  770,
    777, 785, 793, 800, 808, 816, 824, 831, 839, 847, 855, 863, 871, 879,  887,
    896, 904, 912, 920, 929, 937, 945, 954, 962, 971, 980, 988, 997, 1005, 1014,
    1023};

#define BUTTON PA6
#define LED_WHITE_EN PB0
#define LED_WHITE_PWM PB2
#define LED_RED PA5

#define BUTTON_DEBOUNCE_INTERVAL_MS 10
uint32_t buttonDebounceTs = 0;
switch_t button = BUTTON_DEFAULT;

#define BRIGHTNESS_DEFAULT 1023
uint32_t fade_ts = 0;
uint8_t brightness = 255;
bool fadeUp = false;
uint32_t state_change_ts = 0;

typedef enum {
  STATE_IDLE,
  STATE_BATT_LEVEL,
  STATE_WHITE_ON,
  STATE_RED_ON,
  STATE_FADE_WHITE
} State_t;

State_t state = STATE_IDLE;

void buttonInit() {
  DDRA &= ~_BV(BUTTON);
  PUEA |= _BV(BUTTON);
}

static inline void ledWhiteSetBrightnes(uint16_t p_brightness) {
  OCR1A = p_brightness;
}

static inline void ledWhiteOn(uint16_t p_brightness) {
  ledWhiteSetBrightnes(p_brightness);
  PORTB &= ~_BV(LED_WHITE_EN);
  PORTB |= _BV(LED_WHITE_PWM);
  TOCPMCOE |= _BV(TOCC7OE);
}

static inline void ledWhiteOff() {
  ledWhiteSetBrightnes(0);
  PORTB |= _BV(LED_WHITE_EN);
  PORTB &= ~_BV(LED_WHITE_PWM);
  TOCPMCOE &= ~_BV(TOCC7OE);
}

static inline void ledRedOn() { PORTA |= _BV(LED_RED); }
static inline void ledRedOff() { PORTA &= ~_BV(LED_RED); }

void ledsInit() {
  DDRA |= _BV(LED_RED);
  DDRB |= _BV(LED_WHITE_EN);
  DDRB |= _BV(LED_WHITE_PWM);

  TOCPMSA1 = _BV(TOCC7S0);

  TCCR1A = 0;
  TCCR1A |= _BV(COM1A1);
  TCCR1A |= _BV(WGM10) | _BV(WGM11);
  TCCR1B = 0;
  TCCR1B |= _BV(WGM12);
  TCCR1B |= _BV(CS10) | _BV(CS11);

  ledWhiteSetBrightnes(0);
  ledWhiteOff();
  ledRedOff();
}

uint8_t mcusr_mirror __attribute__((section(".noinit")));
void wdt_init(void) {
  mcusr_mirror = MCUSR;
  MCUSR = 0;
  wdt_disable();
}

void processButtons() {
  if (millis() - buttonDebounceTs > BUTTON_DEBOUNCE_INTERVAL_MS) {
    debounce(&button, 0 == (PINA & _BV(BUTTON)));
    buttonDebounceTs = millis();
  }
  serviceButtonWithAutorepeat(&button, 0, 0, 0, millis());
}

inline static void pinChangeIntDisable() { GIMSK &= ~_BV(PCIE0); }

inline static void pinChangeIntEnable() {
  GIFR |= _BV(PCIF0);
  GIMSK |= _BV(PCIE0);
}

void pinChangeIntSetup() { PCMSK0 |= _BV(PCINT6); }

ISR(PCINT0_vect) { pinChangeIntDisable(); }

inline static void sleep() {
  buttonReset(&button);

  // DDRA |= _BV(PA0);
  // PORTA &= ~_BV(PA0);

  DDRA |= _BV(PA1);
  PORTA &= ~_BV(PA1);

  DDRA |= _BV(PA2);
  PORTA &= ~_BV(PA2);

  DDRA |= _BV(PA3);
  PORTA &= ~_BV(PA3);

  DDRA |= _BV(PA4);
  PORTA &= ~_BV(PA4);

  DDRA |= _BV(PA5);
  PORTA &= ~_BV(PA5);

  DDRA &= ~_BV(PA7);
  PUEA |= _BV(PA7);

  DDRB &= ~_BV(PB1);
  PUEB |= _BV(PB1);

  pinChangeIntEnable();
  set_sleep_mode(SLEEP_MODE_PWR_DOWN);
  sleep_enable();
  // wdt_disable();
  sleep_cpu();
  sleep_disable();
  // wdt_enable(WDTO_2S);
}

uint8_t getBatteryLevel();
void bargraphStart(uint8_t level);
void bargraphStop();

void onExit_STATE_IDLE() {
  brightness = 255;
  fadeUp = false;
}

void onExit_STATE_WHITE_ON() { ledWhiteOff(); }

void onEnter_STATE_WHITE_ON(uint16_t p_brightness) {
  state = STATE_WHITE_ON;
  ledWhiteOn(p_brightness);
  state_change_ts = millis();
}

void onEnter_STATE_IDLE() {
  state = STATE_IDLE;
  sleep();
}

void onEnter_STATE_RED_ON() {
  state = STATE_RED_ON;
  ledRedOn();
  state_change_ts = millis();
}

void onExit_STATE_RED_ON() { ledRedOff(); }

void onEnter_STATE_BATT_LEVEL() {
  bargraphStart(getBatteryLevel());
  state = STATE_BATT_LEVEL;
}

void onExit_STATE_BATT_LEVEL() { bargraphStop(); }

void fadeWhite() {
  if (millis() - fade_ts > 10) {
    ledWhiteSetBrightnes(pgm_read_word(&gamma8[brightness]));
    fade_ts = millis();
    if (fadeUp) {
      brightness++;
      if (brightness == 255) {
        fadeUp = false;
      }
    } else {
      brightness--;
      if (30 == brightness) {
        fadeUp = true;
      }
    }
  }
}

void onExit_STATE_FADE_WHITE() {}

void onEnter_STATE_FADE_WHITE() {
  fade_ts = millis();
  state = STATE_FADE_WHITE;
}

void processStateMachine() {
  switch (state) {
  case STATE_IDLE:
    if (isButtonEvent(&button, BUTTON_PRESSED)) {
      onExit_STATE_IDLE();
      onEnter_STATE_BATT_LEVEL();
    }
    break;
  case STATE_BATT_LEVEL:
    if (isButtonEvent(&button, BUTTON_RELEASED)) {
      onExit_STATE_BATT_LEVEL();
      onEnter_STATE_WHITE_ON(BRIGHTNESS_DEFAULT);
    }
    break;
  case STATE_FADE_WHITE:
    fadeWhite();
    if (isButtonEvent(&button, BUTTON_RELEASED)) {
      onExit_STATE_FADE_WHITE();
      onEnter_STATE_WHITE_ON(OCR1A);
    }
    break;
  case STATE_WHITE_ON:
    if (isButtonEvent(&button, BUTTON_RELEASED)) {
      if (millis() - state_change_ts < 3000) {
        onExit_STATE_WHITE_ON();
        onEnter_STATE_RED_ON();
      } else {
        onExit_STATE_WHITE_ON();
        onEnter_STATE_IDLE();
      }
    } else if (isLongPress(&button, millis())) {
      onEnter_STATE_FADE_WHITE();
    }
    break;

  case STATE_RED_ON:
    if (isButtonEvent(&button, BUTTON_PRESSED)) {
      onExit_STATE_RED_ON();
      while (!isButtonEvent(&button, BUTTON_RELEASED)) {
        processButtons();
      }
      onEnter_STATE_IDLE();
    }
    break;

  default:
    break;
  }
}

#define CHARLIE1 PA1
#define CHARLIE2 PA2
#define CHARLIE3 PA3

void charlie(uint8_t x) {
  switch (x) {
  case 0:
    DDRA &= ~_BV(CHARLIE1);
    DDRA &= ~_BV(CHARLIE2);
    DDRA &= ~_BV(CHARLIE3);

    PORTA &= ~_BV(CHARLIE1);
    PORTA &= ~_BV(CHARLIE2);
    PORTA &= ~_BV(CHARLIE3);
    break;
  case 1:
    DDRA |= _BV(CHARLIE1);
    DDRA &= ~_BV(CHARLIE2);
    DDRA |= _BV(CHARLIE3);

    PORTA &= ~_BV(CHARLIE1);
    PORTA &= ~_BV(CHARLIE2);
    PORTA |= _BV(CHARLIE3);
    break;
  case 2:
    DDRA |= _BV(CHARLIE1);
    DDRA &= ~_BV(CHARLIE2);
    DDRA |= _BV(CHARLIE3);

    PORTA |= _BV(CHARLIE1);
    PORTA &= ~_BV(CHARLIE2);
    PORTA &= ~_BV(CHARLIE3);
    break;
  case 3:
    DDRA &= ~_BV(CHARLIE1);
    DDRA |= _BV(CHARLIE2);
    DDRA |= _BV(CHARLIE3);

    PORTA &= ~_BV(CHARLIE1);
    PORTA &= ~_BV(CHARLIE2);
    PORTA |= _BV(CHARLIE3);
    break;
  case 4:
    DDRA |= _BV(CHARLIE1);
    DDRA |= _BV(CHARLIE2);
    DDRA &= ~_BV(CHARLIE3);

    PORTA |= _BV(CHARLIE1);
    PORTA &= ~_BV(CHARLIE2);
    PORTA &= ~_BV(CHARLIE3);
    break;
  case 5:
    DDRA |= _BV(CHARLIE1);
    DDRA |= _BV(CHARLIE2);
    DDRA &= ~_BV(CHARLIE3);

    PORTA &= ~_BV(CHARLIE1);
    PORTA |= _BV(CHARLIE2);
    PORTA &= ~_BV(CHARLIE3);
    break;
  case 6:
    DDRA &= ~_BV(CHARLIE1);
    DDRA |= _BV(CHARLIE2);
    DDRA |= _BV(CHARLIE3);

    PORTA &= ~_BV(CHARLIE1);
    PORTA |= _BV(CHARLIE2);
    PORTA &= ~_BV(CHARLIE3);
    break;
  default:
    break;
  }
}

uint8_t currCharlie = 0;
uint8_t bargraphLevel = 0;
void bargraphStart(uint8_t level) {
  bargraphLevel = level;
  TCCR2A = 0;
  TCCR2B = 0;
  TCCR2B |= _BV(WGM22);
  TCCR2B |= _BV(CS20);
  TIMSK2 |= _BV(OCIE2A);
  OCR2A = 10000;
}

void bargraphStop() {
  TCCR2B = 0;
  charlie(0);
}

ISR(TIMER2_COMPA_vect) {
  if (currCharlie <= bargraphLevel) {
    charlie(currCharlie);
  } else {
    charlie(0);
  }

  currCharlie++;
  if (currCharlie > 6) {
    currCharlie = 0;
  }
}

#define CHANNEL_BATTERY 0

uint8_t adcInProgress = 0;

inline static void sleepWhileADC() {
  adcInProgress = 1;
  while (adcInProgress) {
    set_sleep_mode(SLEEP_MODE_ADC);
    sleep_mode();
  }
}

ISR(ADC_vect) {
  adcInProgress = 0;
  // nothing, just wake up
}

uint16_t adcReadChannel(uint8_t channel) {
  ADMUXA = channel;
  ADCSRA |= _BV(ADSC);
  // sleepWhileADC();
  loop_until_bit_is_clear(ADCSRA, ADSC);
  uint16_t ret = ADC;
  return ret;
}

inline static void adcSetup() {
  PRR &= ~_BV(PRADC);
  DIDR0 |= _BV(ADC0D);
  ADCSRA = 0;
  ADMUXB = _BV(REFS1); // use internal 2.2V reference
  ADCSRA = _BV(ADEN) | _BV(ADPS2) | _BV(ADPS1) | _BV(ADPS0) | _BV(ADIE);
}

inline static void adcDisable() {
  ADCSRA = 0;
  PRR |= _BV(PRADC);
}

uint16_t adcGetBatteryVoltage() {
  adcSetup();
  adcReadChannel(CHANNEL_BATTERY);
  uint32_t lsb = adcReadChannel(CHANNEL_BATTERY);
  adcDisable();
  return lsb * 220 * 2 / 1024;
}

uint8_t getBatteryLevel() {
  uint16_t voltage = adcGetBatteryVoltage();
  if (voltage <= 320) {
    return 1;
  } else if (voltage <= 340) {
    return 2;
  } else if (voltage <= 360) {
    return 3;
  } else if (voltage <= 370) {
    return 4;
  } else if (voltage <= 400) {
    return 5;
  } else if (voltage <= 420) {
    return 6;
  } else if (voltage > 420) {
    return 6;
  }
}

uint8_t c = 0;

void main() {
  // wdt_init();
  // wdt_reset();
  buttonInit();
  millisInit();
  ledsInit();
  pinChangeIntSetup();
  sei();

  // wdt_enable(WDTO_2S);

  onEnter_STATE_IDLE();

  while (1) {
    processButtons();
    processStateMachine();
    wdt_reset();
  }

  // bargraphStart(0);
  // while (1) {
  //   bargraphLevel = 0;
  //   _delay_ms(500);
  //   bargraphLevel = 1;
  //   _delay_ms(500);
  //   bargraphLevel = 2;
  //   _delay_ms(500);
  //   bargraphLevel = 3;
  //   _delay_ms(500);
  //   bargraphLevel = 4;
  //   _delay_ms(500);
  //   bargraphLevel = 5;
  //   _delay_ms(500);
  //   bargraphLevel = 6;
  //   _delay_ms(500);
  // }
}

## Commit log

2021-09-28 Add electronics design files
    [LUXEON 3030 2D Round LES.step, led_driver.kicad_sch, solar_charger.kicad_sch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]
2021-09-28 Add mechanical files
    [bezel.FCStd]
2021-11-23 Make board smaller, Fix bad cap orientation, Add a diode to reduce quescient current
    [CLA1B-MKW-XD0E0E73.STEP, battery.kicad_sch, c-1571407-2-j-3d.stp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]
2021-12-30 Add battery level measurement and display
2021-12-30 Fix PCB thickness, add some measirements to PCB
    [solar_lantern.kicad_pcb]
2022-01-23 Reformat code stolen from Arduino
2022-01-23 Add a function to choose light output for white leds
2022-01-23 Nicen schematics a bit
    [battery.kicad_sch, led_driver.kicad_sch, solar_charger.kicad_sch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]
2022-01-29 Add CERN-OHL_S licence
    [battery.kicad_sch, led_driver.kicad_sch, solar_charger.kicad_sch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]
2022-01-29 Add shematics in PDF
    [solar_lantern.kicad_pcb]
2022-11-04 Make fade continue on repeated long press. Switch off instead of moving to another state after 3s timeout
